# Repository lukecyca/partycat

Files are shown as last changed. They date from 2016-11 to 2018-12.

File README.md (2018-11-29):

partycat led controller
=======================

Partycat is a small ESP8266-based controller for WS2812 LED strips.

Features
--------

- Level-shifted GPIO pins, including one for a WS2812 strip
- A footprint that lets you solder the end of the strip right to the board
- WS2812 is on the I2S port, so it can use DMA using this hack (or the Arduino-compatible version)
- Programming using a standard 6-pin FTDI cable (no onboard USB you wuss)

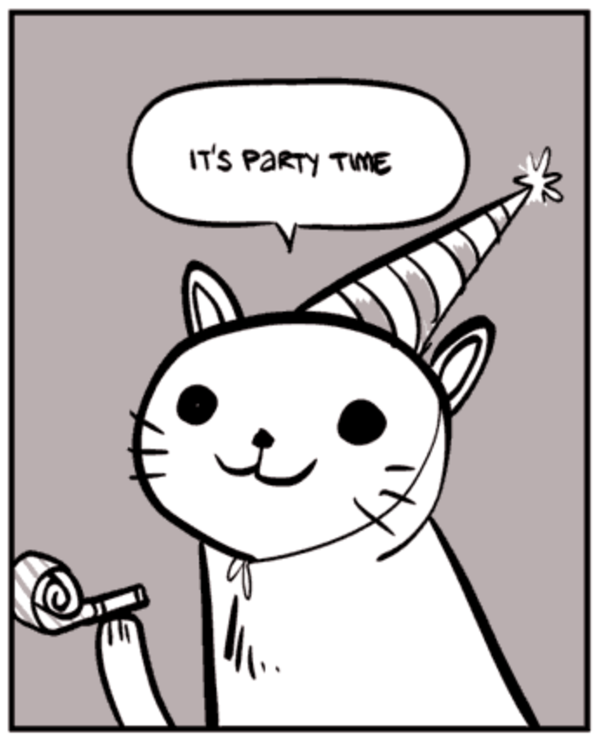
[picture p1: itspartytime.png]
It's Party Time


Illustration Credit: http://nedroid.com/2009/05/party-cat-full-series/

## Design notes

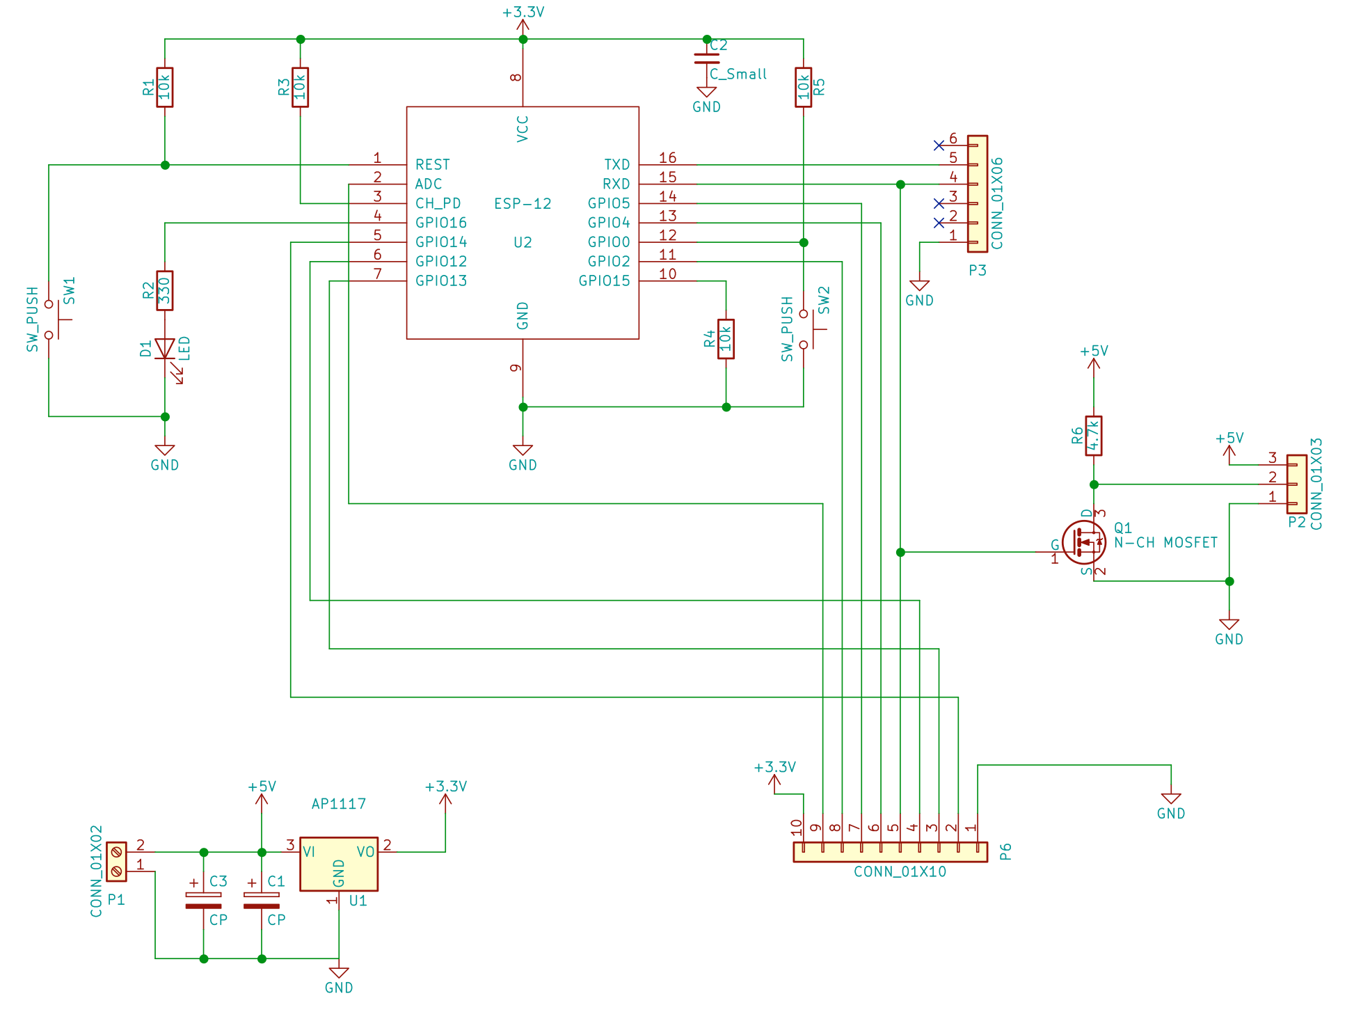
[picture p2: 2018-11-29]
schematic.png

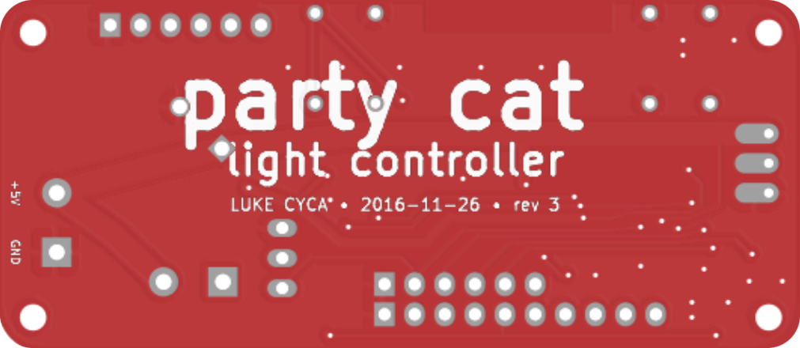
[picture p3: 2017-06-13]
Docs/Back.png

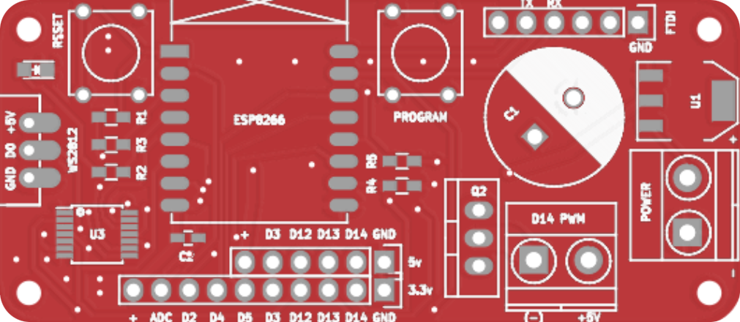
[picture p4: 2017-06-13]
Docs/Front.png

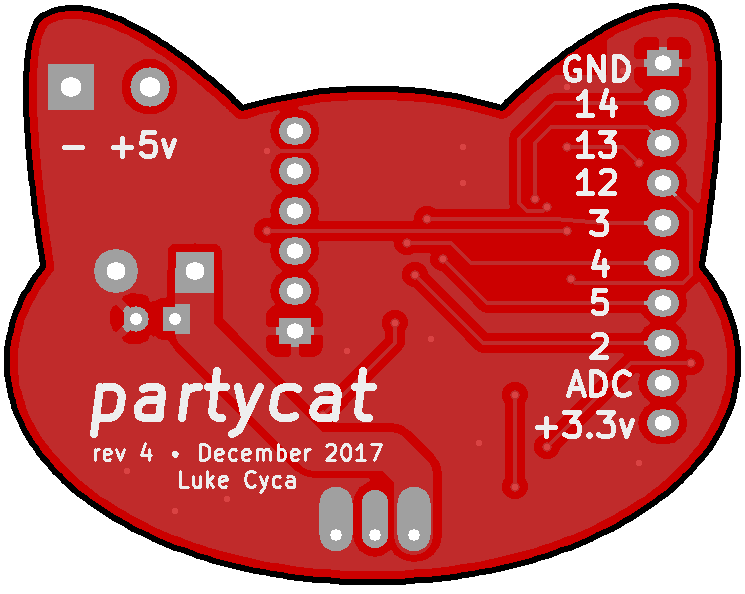
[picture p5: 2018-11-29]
gerbers/bottom.png

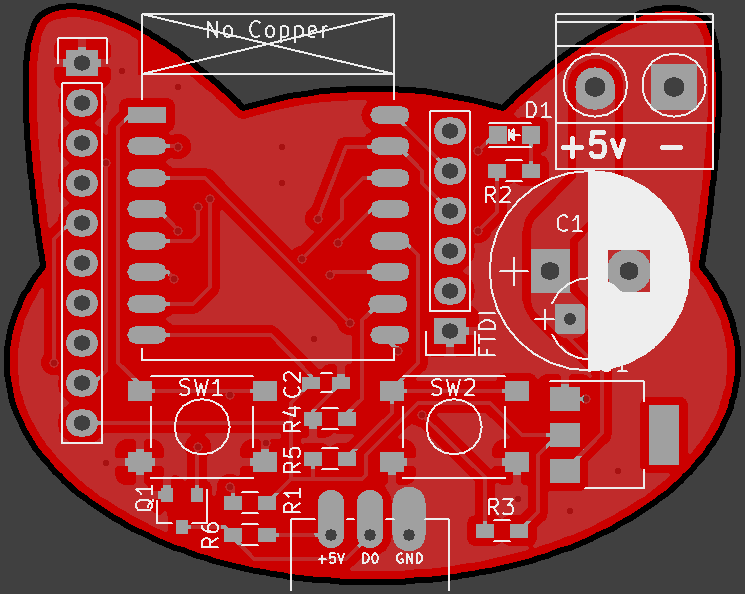
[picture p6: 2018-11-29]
gerbers/top.png

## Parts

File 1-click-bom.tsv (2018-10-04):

References | Qty | Description | Part Number
C1 | 1 | CP Polarised capacitor C Radial D12.5 L25 P5 | 399-6102-ND
C2 | 1 | C Small Unpolarized capacitor 0603 HandSoldering | 311-3700-1-ND
D1 | 1 | LED 0805 | 160-1427-1-ND
P1, P5 | 2 | CONN 01X02 Connector 01x02 TerminalBlock Pheonix MKDS1.5-2pol
P2 | 1 | CONN 01X03 Connector 01x03 WS2812 Strip | 104990000-ND
P4, P3 | 2 | CONN 01X06 Connector 01x06 Pin Header Straight 1x06
Q2 | 1 | Q NMOS GDS Transistor N-MOSFET (general) TO-220 Neutral123 Vertical | 497-3185-5-ND
R2 | 1 | R 330 Resistor 0603 HandSoldering | CR0603-JW-331ELFCT-ND
R4, R3, R5, R1 | 4 | R 10k Resistor 0603 HandSoldering | CR0603-JW-103ELFCT-ND
SW2, SW1 | 2 | SW PUSH Button SMALL | 679-2428-ND
U1 | 1 | AP1117 Fixed/Adjustable 1A Low Dropout regulator, Positive SOT-223 | AZ1117IH-ADJTRG1DICT-ND
U2 | 1 | ESP-12 ESP8622 module, 16 pins, 2mm, PCB antenna ESP-07v2-smd
U3 | 1 | SN54AHCT125 SSOP-14 | 296-4653-1-ND

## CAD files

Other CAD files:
gerbers/partycat-F.Paste.dxf

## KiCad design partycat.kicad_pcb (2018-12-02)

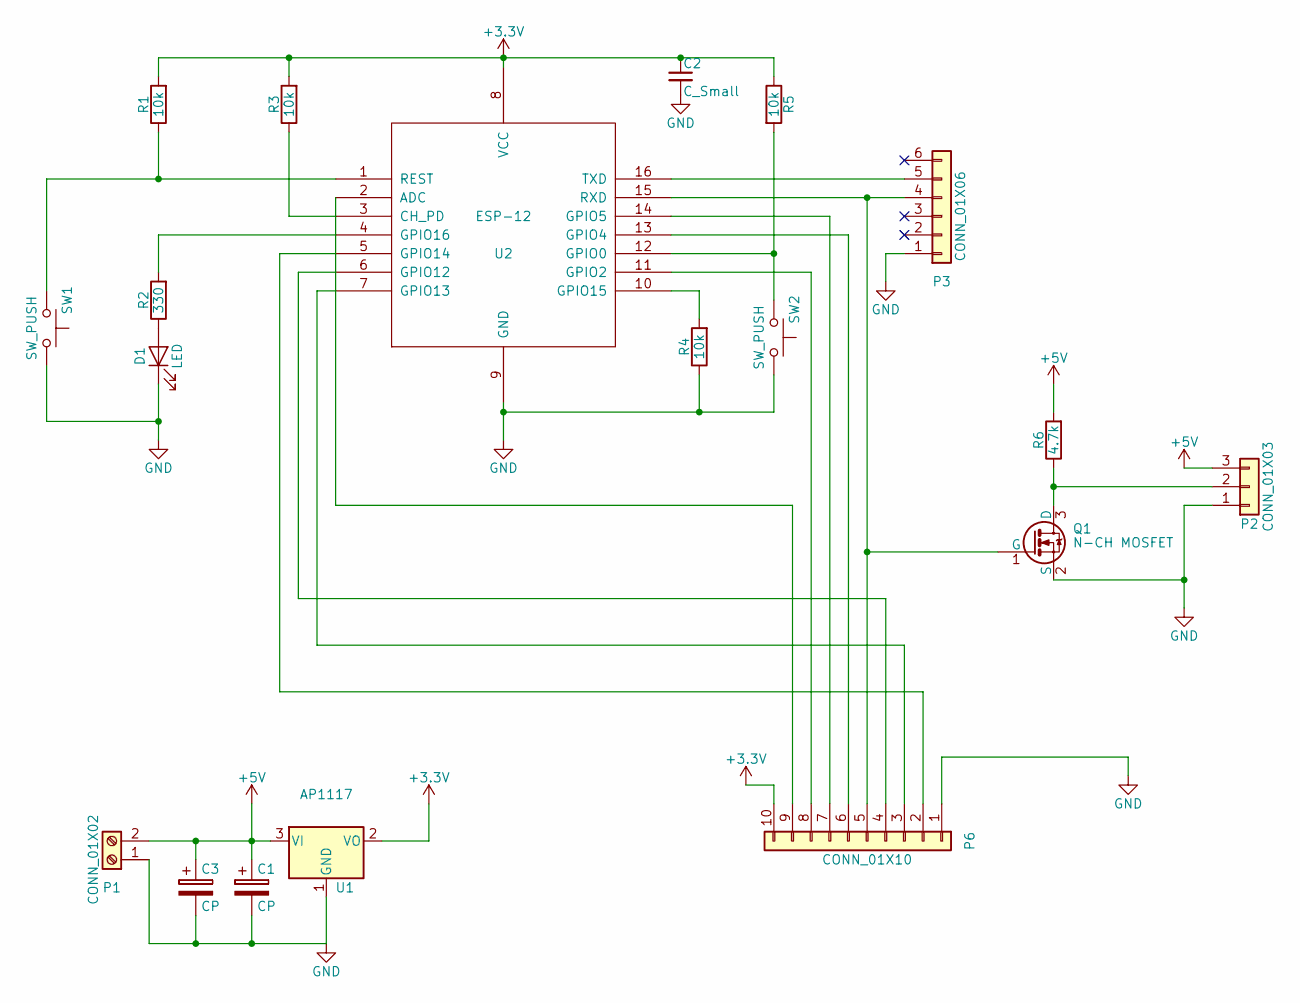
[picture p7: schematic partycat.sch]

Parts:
C1: CP; CP_Radial_D12.5mm_P5.00mm
C2: C_Small; C_0603_HandSoldering
C3: CP; CP_Radial_D5.0mm_P2.50mm
D1: LED; LED_0805
P1: CONN_01X02; TerminalBlock_Pheonix_MKDS1.5-2pol
P2: CONN_01X03; WS2812_Strip
P3: CONN_01X06; Pin_Header_Straight_1x06
P6: CONN_01X10; Pin_Header_Straight_1x10
Q1: N-CH MOSFET; SOT-23
R1, R3, R4, R5: 10k; R_0603_HandSoldering
R2: 330; R_0603_HandSoldering
R6: 4.7k; R_0603_HandSoldering
SW1, SW2: SW_PUSH; SW_SPST_PTS645
U1: AP1117; SOT-223
U2: ESP-12; ESP-07v2-smd

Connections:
+3V3: C2.1, P6.10, R1.2, R3.2, R5.1, U1.2 (VO), U2.8 (VCC)
+5V: C1.1, C3.1, P1.2, P2.3, R6.2, U1.3 (VI)
GND: C1.2, C2.2, C3.2, D1.1 (K), P1.1, P2.1, P3.1, P6.1, Q1.2 (S), R4.1, SW1.1, SW2.1, U1.1 (GND), U2.9 (GND); also elsewhere on the board
unnamed: D1.2 (A), R2.1
unnamed: P2.2, Q1.3 (D), R6.1
unnamed 5: P3.4, P6.5, Q1.1 (G), U2.15 (RXD); also elsewhere on the board
unnamed 6: P3.5, U2.16 (TXD); also elsewhere on the board
unnamed: P6.2, U2.5 (GPIO14)
unnamed: P6.3, U2.7 (GPIO13)
unnamed: P6.4, U2.6 (GPIO12)
unnamed: P6.6, U2.13 (GPIO4)
unnamed: P6.7, U2.14 (GPIO5)
unnamed: P6.8, U2.11 (GPIO2)
unnamed: P6.9, U2.2 (ADC)
unnamed: R1.1, SW1.2, U2.1 (REST)
unnamed: R2.2, U2.4 (GPIO16)
unnamed: R3.1, U2.3 (CH_PD)
unnamed: R4.2, U2.10 (GPIO15)
unnamed: R5.2, SW2.2, U2.12 (GPIO0)

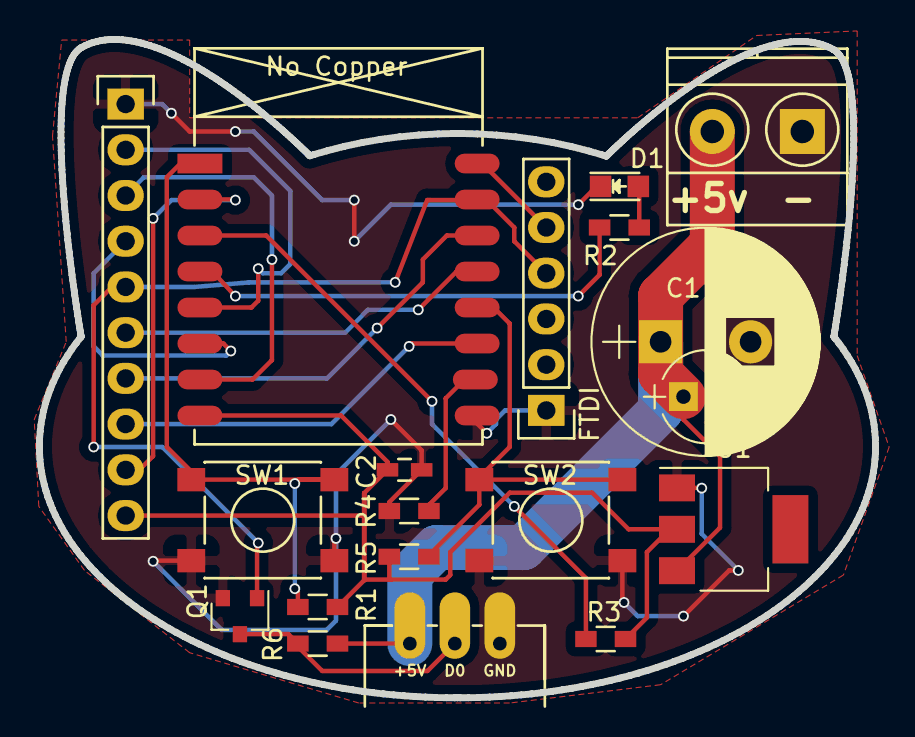
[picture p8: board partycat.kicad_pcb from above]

Board: 2 copper layers, 46.5 x 36.6 mm, 19 parts (0 on the bottom side), 19 nets.

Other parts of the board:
FTDI: CONN_01X06; Pin_Header_Straight_1x06

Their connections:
GND: FTDI.1; also elsewhere on the board
unnamed 5: FTDI.4; also elsewhere on the board
unnamed 6: FTDI.5; also elsewhere on the board

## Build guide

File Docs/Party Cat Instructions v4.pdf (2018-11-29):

# Partycat Light Controller Kit

By Luke Cyca | Nov 22, 2018 | Revision 4

Congratulations on your purchase of the partycat light controller kit! This board uses a ESP8266 wifi-enabled microcontroller to control a string of WS2812-compatible RGB LEDs. Have fun!

## Building

All components are on one side, so it’s easy to populate, easy to bake, and easy to tape or hotglue the finished board down with your LED strip.

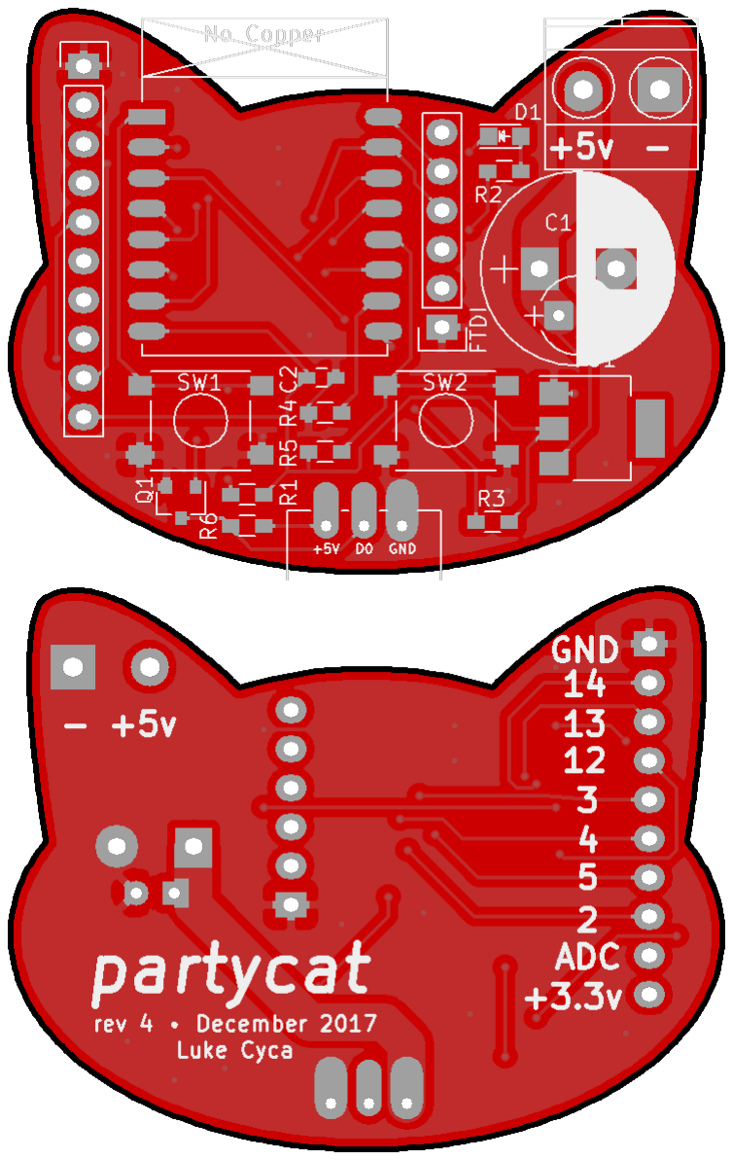
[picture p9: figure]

R1: 10kΩ Resistor (red)
R2: 332Ω Resistor (green)
R3: 10kΩ Resistor (red)
R4: 10kΩ Resistor (red)
R5: 10kΩ Resistor (red)
R6: 4.7kΩ Resistor (blue)

C1: 1000µF 10V Electrolytic Capacitor (accommodates two sizes of caps) C2: 0.1µF Ceramic Capacitor (yellow)

U1: AP1117E33G-13
U2: ESP8266 Module 7/12/12E/12F

D1: Red LED
Q1: BC807 MOSFET

MISC:
2x Pushbuttons
1x Two-terminal screw terminal blocks 0.1” 6-pin FTDI programming header
A short string of two WS2812 GRBW LEDs (included so you can test your board)

## SMD Hand-Soldering Pro Tips

Start with the smallest components first.

For each component, put a bit of solder on one pad first. Then while keeping the solder hot with the soldering iron in one hand, place the component with tweezers to tack it in place. Solder a pin on the opposite side. Then go back and resolder the first, and all additional pins.

Use extra solder flux to help the solder flow freely.

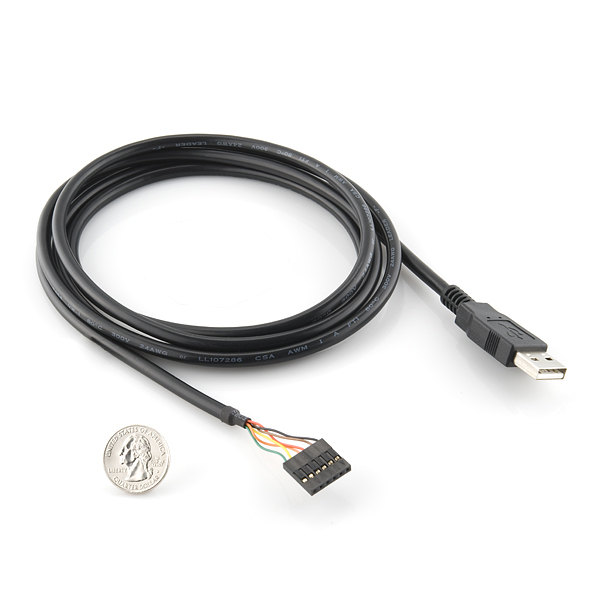
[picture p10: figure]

## Programming

To program this board you need a FTDI cable with 3.3v logic level, like this one from Sparkfun: https://new.sparkfun.com/products/9717

The black wire is GND. Make sure you plug it in the right way around. Some other FTDI cables have a different pinout. Make sure yours is the same as the Sparkfun one:

## RTS, RX, TX, 5V, CTS, GND

You can program it using the Arduino IDE along with
the ESP8266 board add-on from:
http://github.com/esp8266/Arduino

To put the partycat into programming mode, hold down the PROGRAM button while pressing the RESET button. Then upload your sketch.

This board is set up to use the i²s output (pin 3) to control the lights with DMA, allowing relatively high frame rates without tying up the processor.

The recommended library for use with Partycat is NeoPixelBus because it supports DMA output on pin 3, and a wide range of pixel devices including RGBW. https://github.com/Makuna/NeoPixelBus

A simple example sketch is available at
https://github.com/lukecyca/partycat-blinky

Since pin 3 is also used by the ESP8266 for UART RX, unplug the FTDI cable after programming for best results driving the WS2812s.

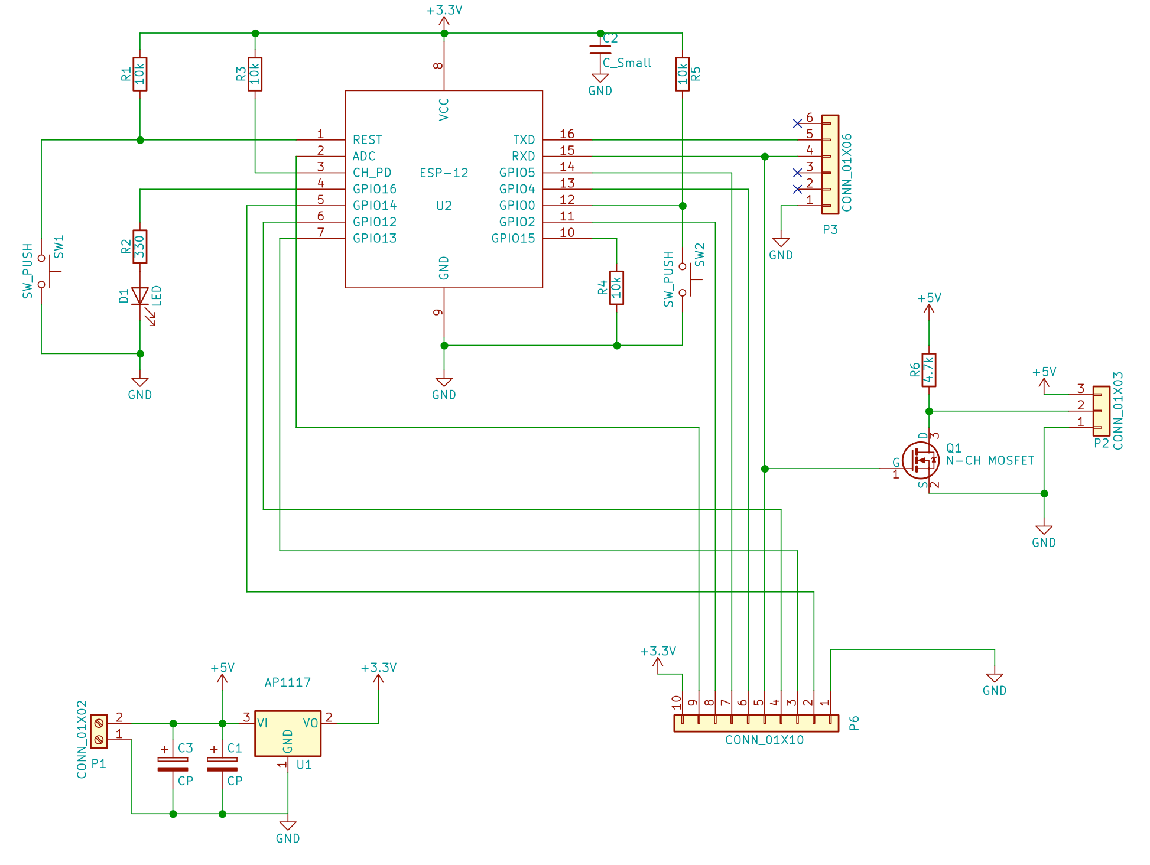
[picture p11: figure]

## Schematic

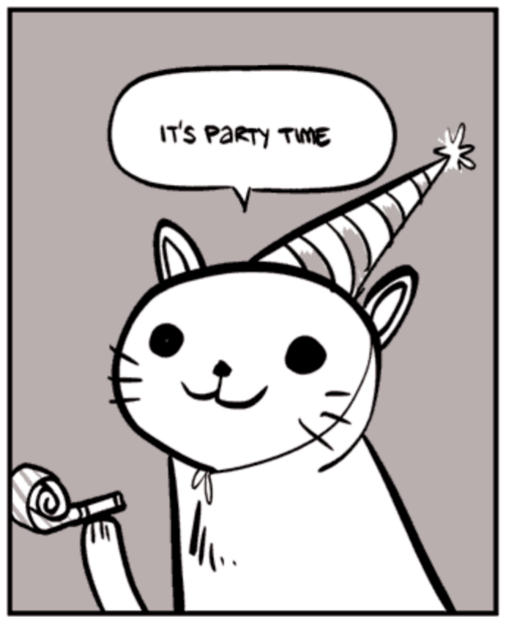
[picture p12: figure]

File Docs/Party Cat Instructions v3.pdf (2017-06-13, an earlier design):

# Partycat Light Controller Kit

By Luke Cyca | Nov 26, 2016 | Revision 3

Congratulations on your purchase of the partycat light controller kit! This board uses a ESP8266 wifi-enabled microcontroller to control a string of WS2812-compatible RGB LEDs, plus another channel of high-current PWM dimming. Have fun!

## Building

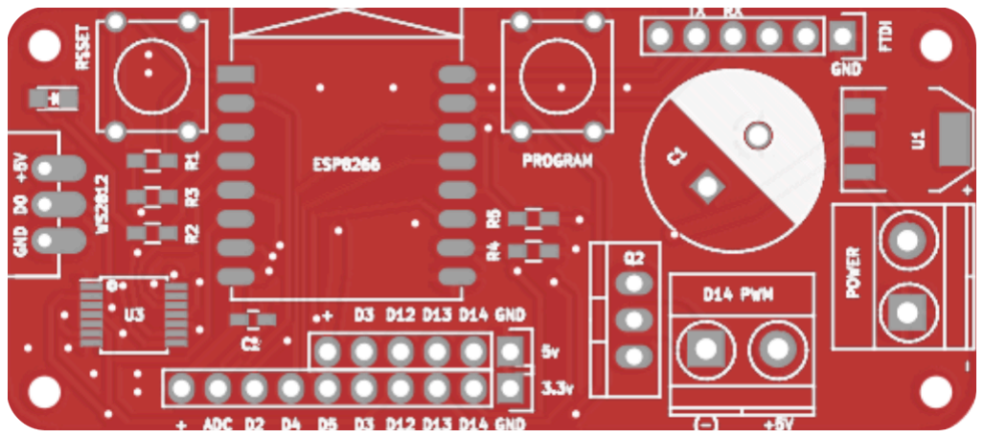
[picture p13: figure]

All components are on one side, so it’s easy to populate, easy to bake, and easy to tape or hot-glue the finished board down with your LED strip.

R1: 10kΩ Resistor (blue)
R2: 332Ω Resistor (pink)
R3: 10kΩ Resistor (blue)
R4: 10kΩ Resistor (blue)
R5: 10kΩ Resistor (blue)

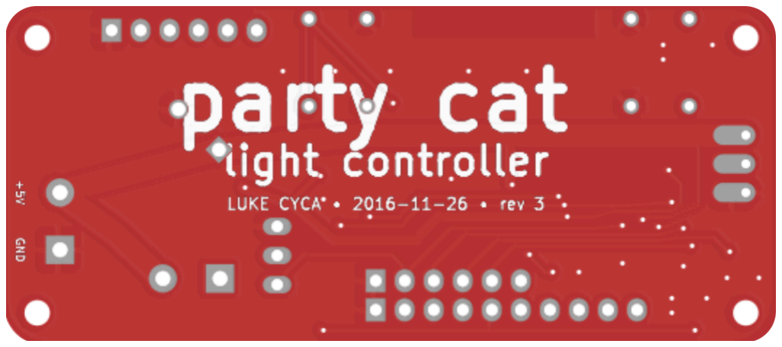
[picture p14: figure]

C1: 100µF 25V Electrolytic Capacitor C2: 0.1µF Ceramic Capacitor (yellow)

U1: AP1117E33G-13
U2: ESP8266 Module 7/12/12E/12F U3: SN74AHCT125

D1: Red LED
Q2: STB24NF10 MOSFET

MISC:
2x Pushbuttons
2x Two-terminal screw terminal blocks
0.1” pin headers
A short string of two WS2812 LEDs (included so you can test your board)

## SMD Hand-Soldering Pro Tips

Start with the smallest components first.

For each component, put a bit of solder on one pad first. Then while keeping the solder hot with the soldering iron in one hand, place the component with tweezers to tack it in place. Solder a pin on the opposite side. Then go back and resolder the first, and all additional pins.

Use extra solder flux to help the solder flow freely.


## Programming

To program this board you need a FTDI cable with 3.3v logic level, like this one from Sparkfun: https://new.sparkfun.com/products/9717

The black wire is GND. Make sure you plug it in the right way around. Some other FTDI cables have a different pinout. Make sure yours is the same as the Sparkfun one:

## RTS, RX, TX, 5V, CTS, GND

You can program it using the Arduino IDE along with
the ESP8266 board add-on from:
http://github.com/esp8266/Arduino

To put the partycat into programming mode, hold down the PROGRAM button while pressing the RESET button. Then upload your sketch.

This board is set up to use the i²c output (pin 3) to control the lights with DMA, allowing relatively high frame rates without completely tying up the processor. Use will need WS2812 i2c library: https://github.com/JoDaNl/esp8266_ws2812_i2s

Here is an example sketch you can use to test your board: https://github.com/lukecyca/partycat-blinky

The partycat is also compatible with other NeoPixel libraries including NeoPixelBus: https://github.com/Makuna/NeoPixelBus

Since pin 3 is also used by the ESP8266 for UART RX, unplug the FTDI cable after programming for best results driving the WS2812s.

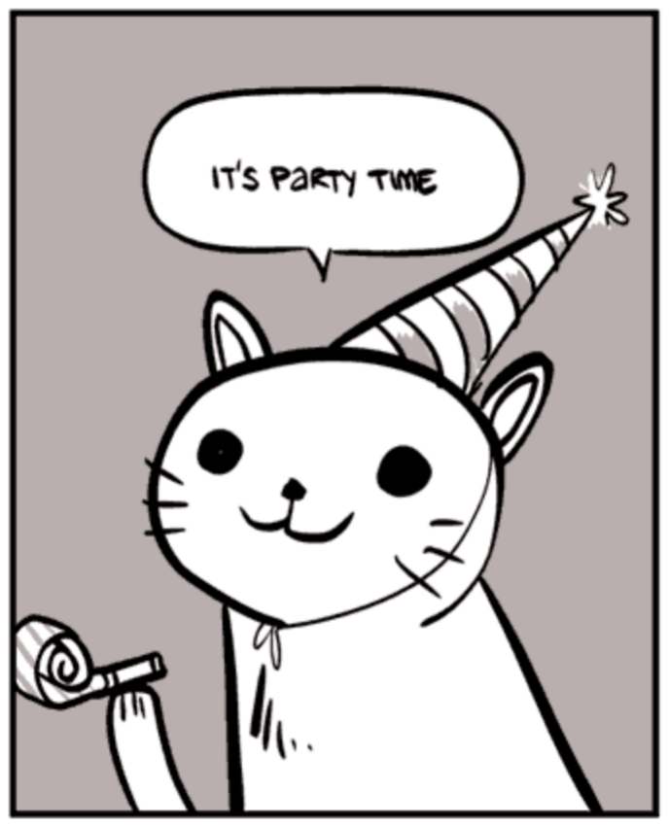
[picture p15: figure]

## Other Features

Some GPIO pins are broken out with both 3.3v and 5v variants. The 3.3v one is directly connected to the ESP8266 pin so it can be used as either input or output. The corresponding 5v variant pin can only be used as an output.

There is a high-current-sinking MOSFET connected to PIN D14 that can be used to drive a string of regular LEDs, a motor, etc. I have used this for driving a string of white LEDs to reinforce the WS2812s when I want a very bright white. Since it is sinking and switches the low side, it can be used to drive higher voltage (ex: 12v) LED strips.

## Schematic

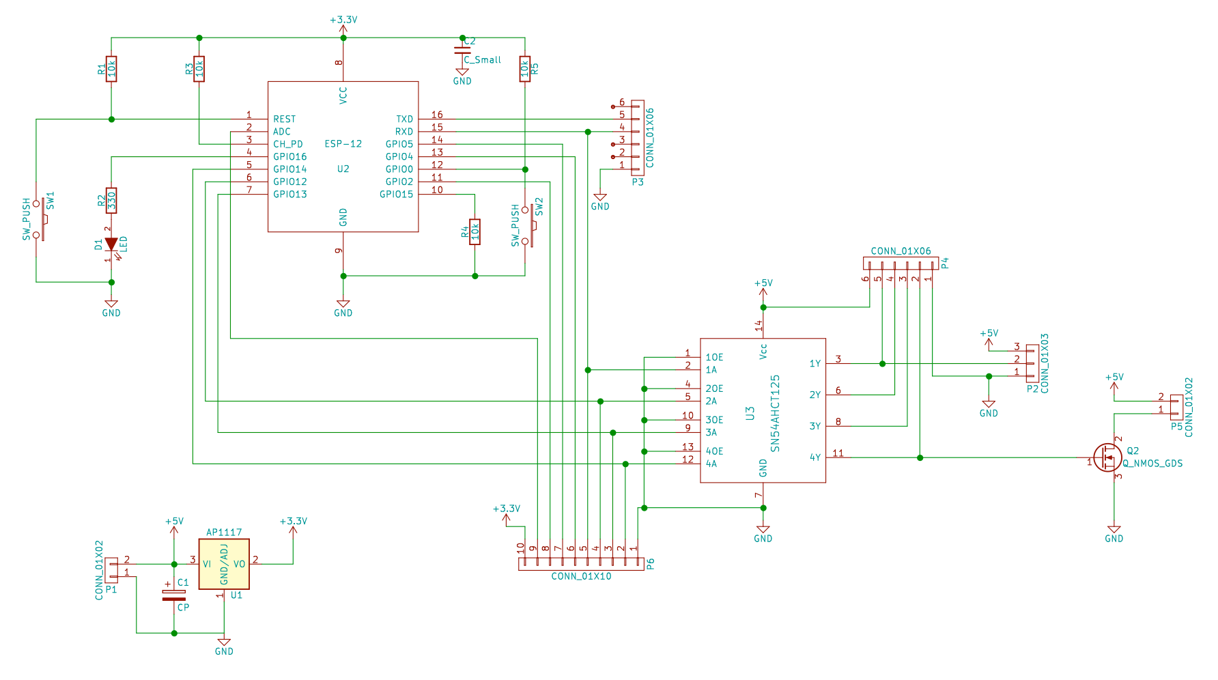
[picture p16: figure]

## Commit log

2016-11-01 Added some Digikey part numbers to BOM
    [1-click-bom.tsv]
2017-06-13 Added docs, panelized gerbers, and renamed files (all versions will use this repo)
    [partycat-v2.kicad_pcb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]
2018-10-04 Update 1-click-bom.tsv
    Added more digikey part numbers to BOM
    [1-click-bom.tsv]
2018-11-29 More v4 updates
    [partycat-panel-B.Cu.gbl, partycat-panel-B.Mask.gbs, partycat-panel-B.SilkS.gbo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]
2018-12-01 Add SVG of soldermask (for a stencil)
2018-12-02 Add solder paste DXF
    [partycat-F.Paste.dxf, partycat.kicad_pcb]
